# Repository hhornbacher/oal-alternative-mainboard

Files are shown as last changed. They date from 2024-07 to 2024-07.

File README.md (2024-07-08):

# Alternative mainboard for OpenAutoLab

The [OpenAutoLab](https://github.com/kauzerei/openautolab) is a automatic film processor developed by [@kauzerei](https://github.com/kauzerei).

I've designed an alternative mainboard based on an ESP32-S3 to also support transfer of development processes via BLE (and in future maybe WiFI with web interface).

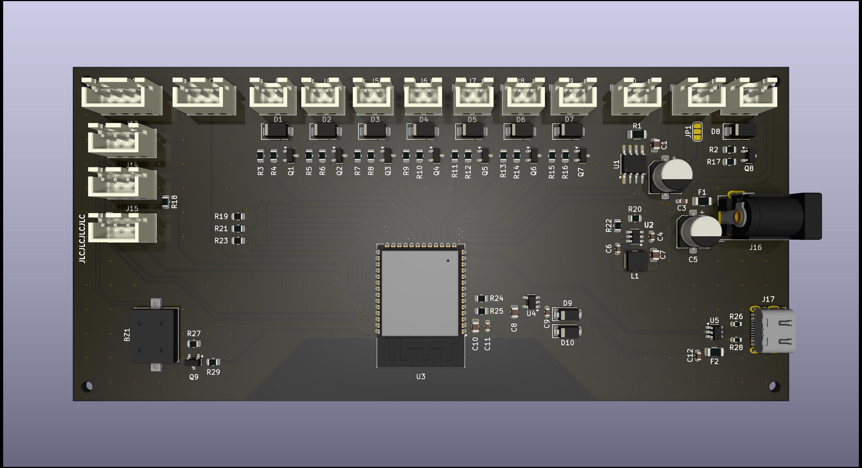
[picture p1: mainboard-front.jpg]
PCB rendering front


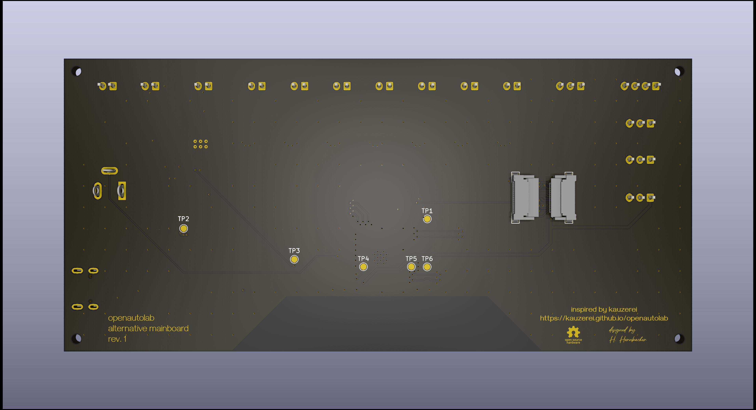
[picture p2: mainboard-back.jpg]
PCB rendering back


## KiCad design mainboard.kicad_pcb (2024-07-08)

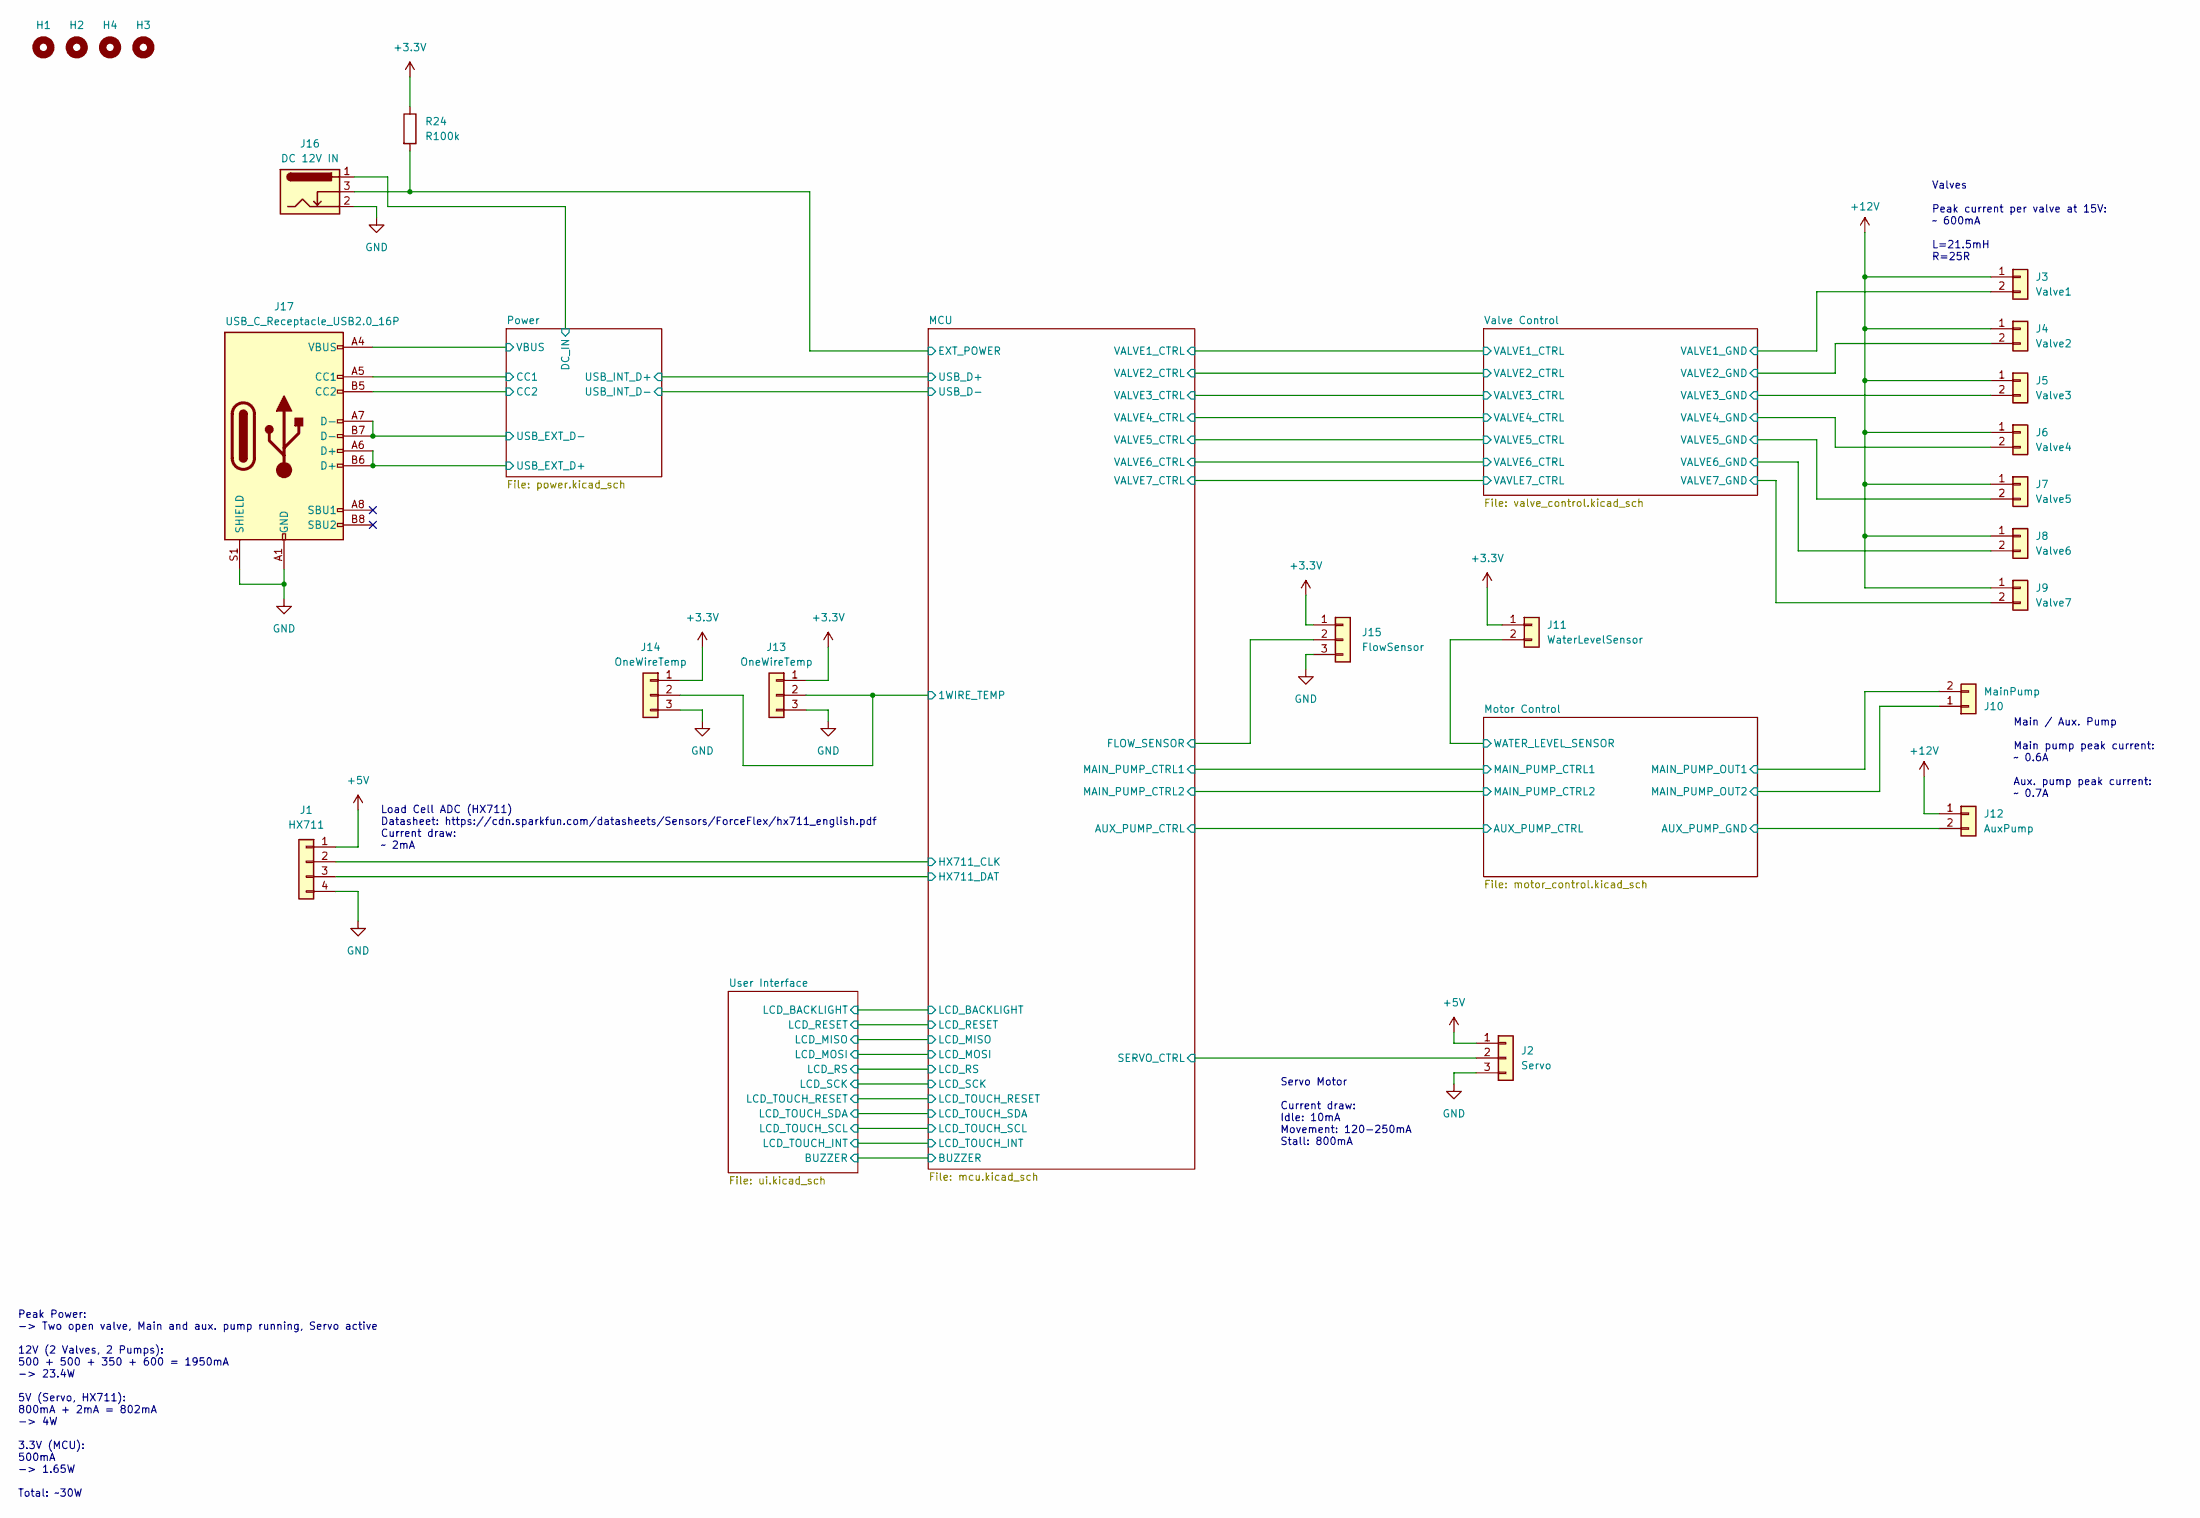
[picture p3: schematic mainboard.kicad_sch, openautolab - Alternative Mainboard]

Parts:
H1, H2, H3, H4: MountingHole; MountingHole_2.2mm_M2
J1: HX711; JST_XH_B4B-XH-A_1x04_P2.50mm_Vertical
J2: Servo; JST_XH_B3B-XH-A_1x03_P2.50mm_Vertical
J3: Valve1; JST_XH_B2B-XH-A_1x02_P2.50mm_Vertical
J4: Valve2; JST_XH_B2B-XH-A_1x02_P2.50mm_Vertical
J5: Valve3; JST_XH_B2B-XH-A_1x02_P2.50mm_Vertical
J6: Valve4; JST_XH_B2B-XH-A_1x02_P2.50mm_Vertical
J7: Valve5; JST_XH_B2B-XH-A_1x02_P2.50mm_Vertical
J8: Valve6; JST_XH_B2B-XH-A_1x02_P2.50mm_Vertical
J9: Valve7; JST_XH_B2B-XH-A_1x02_P2.50mm_Vertical
J10: MainPump; JST_XH_B2B-XH-A_1x02_P2.50mm_Vertical
J11: WaterLevelSensor; JST_XH_B2B-XH-A_1x02_P2.50mm_Vertical
J12: AuxPump; JST_XH_B2B-XH-A_1x02_P2.50mm_Vertical
J13, J14: OneWireTemp; JST_XH_B3B-XH-A_1x03_P2.50mm_Vertical
J15: FlowSensor; JST_XH_B3B-XH-A_1x03_P2.50mm_Vertical
J16: DC 12V IN; BarrelJack_Wuerth_6941xx301002; Mouser Part Number 710-694106301002
J17: USB_C_Receptacle_USB2.0_16P; USB_C_Receptacle_JAE_DX07S016JA1R1500; Mouser Part Number 656-DX07S016JA1R1500
R24: R100k; R_0805_2012Metric; Mouser Part Number 660-RK73B2ATTD104J

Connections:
+3.3V: J11.1, J13.1, J14.1, J15.1, R24.1; also elsewhere on the board
+5V: J1.1, J2.1; also elsewhere on the board
+12V: J3.1, J4.1, J5.1, J6.1, J7.1, J8.1, J9.1, J12.1; also elsewhere on the board
/MCU/1WIRE_TEMP: J13.2, J14.2; also elsewhere on the board
/MCU/EXT_POWER: J16.3, R24.2; also elsewhere on the board
/MCU/FLOW_SENSOR: J15.2; also elsewhere on the board
/MCU/HX711_CLK: J1.2; also elsewhere on the board
/MCU/HX711_DAT: J1.3; also elsewhere on the board
/MCU/SERVO_CTRL: J2.2; also elsewhere on the board
/Motor Control/AUX_PUMP_GND: J12.2; also elsewhere on the board
/Motor Control/MAIN_PUMP_OUT1: J10.2; also elsewhere on the board
/Motor Control/MAIN_PUMP_OUT2: J10.1; also elsewhere on the board
/Motor Control/WATER_LEVEL_SENSOR: J11.2; also elsewhere on the board
/Power/CC1: J17.A5 (CC1); also elsewhere on the board
/Power/CC2: J17.B5 (CC2); also elsewhere on the board
/Power/DC_IN: J16.1; also elsewhere on the board
/Power/USB_EXT_D+: J17.A6 (D+), J17.B6 (D+); also elsewhere on the board
/Power/USB_EXT_D-: J17.A7 (D-), J17.B7 (D-); also elsewhere on the board
/Power/VBUS: J17.A4 (VBUS), J17.A9 (VBUS), J17.B4 (VBUS), J17.B9 (VBUS); also elsewhere on the board
/Valve Control/VALVE1_GND: J3.2; also elsewhere on the board
/Valve Control/VALVE2_GND: J4.2; also elsewhere on the board
/Valve Control/VALVE3_GND: J5.2; also elsewhere on the board
/Valve Control/VALVE4_GND: J6.2; also elsewhere on the board
/Valve Control/VALVE5_GND: J7.2; also elsewhere on the board
/Valve Control/VALVE6_GND: J8.2; also elsewhere on the board
/Valve Control/VALVE7_GND: J9.2; also elsewhere on the board
GND: J1.4, J2.3, J13.3, J14.3, J15.3, J16.2, J17.A1 (GND), J17.A12 (GND), J17.B1 (GND), J17.B12 (GND), J17.S1 (SHIELD); also elsewhere on the board

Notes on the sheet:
Peak Power: -> Two open valve, Main and aux. pump running, Servo active 12V (2 Valves, 2 Pumps): 500 + 500 + 350 + 600 = 1950mA -> 23.4W 5V (Servo, HX711): 800mA + 2mA = 802mA -> 4W 3.3V (MCU): 500mA -> 1.65W Total: ~30W
Load Cell ADC (HX711) Datasheet: https://cdn.sparkfun.com/datasheets/Sensors/ForceFlex/hx711_english.pdf Current draw: ~ 2mA
Valves Peak current per valve at 15V: ~ 600mA L=21.5mH R=25R
Servo Motor Current draw: Idle: 10mA Movement: 120-250mA Stall: 800mA
Main / Aux. Pump Main pump peak current: ~ 0.6A Aux. pump peak current: ~ 0.7A

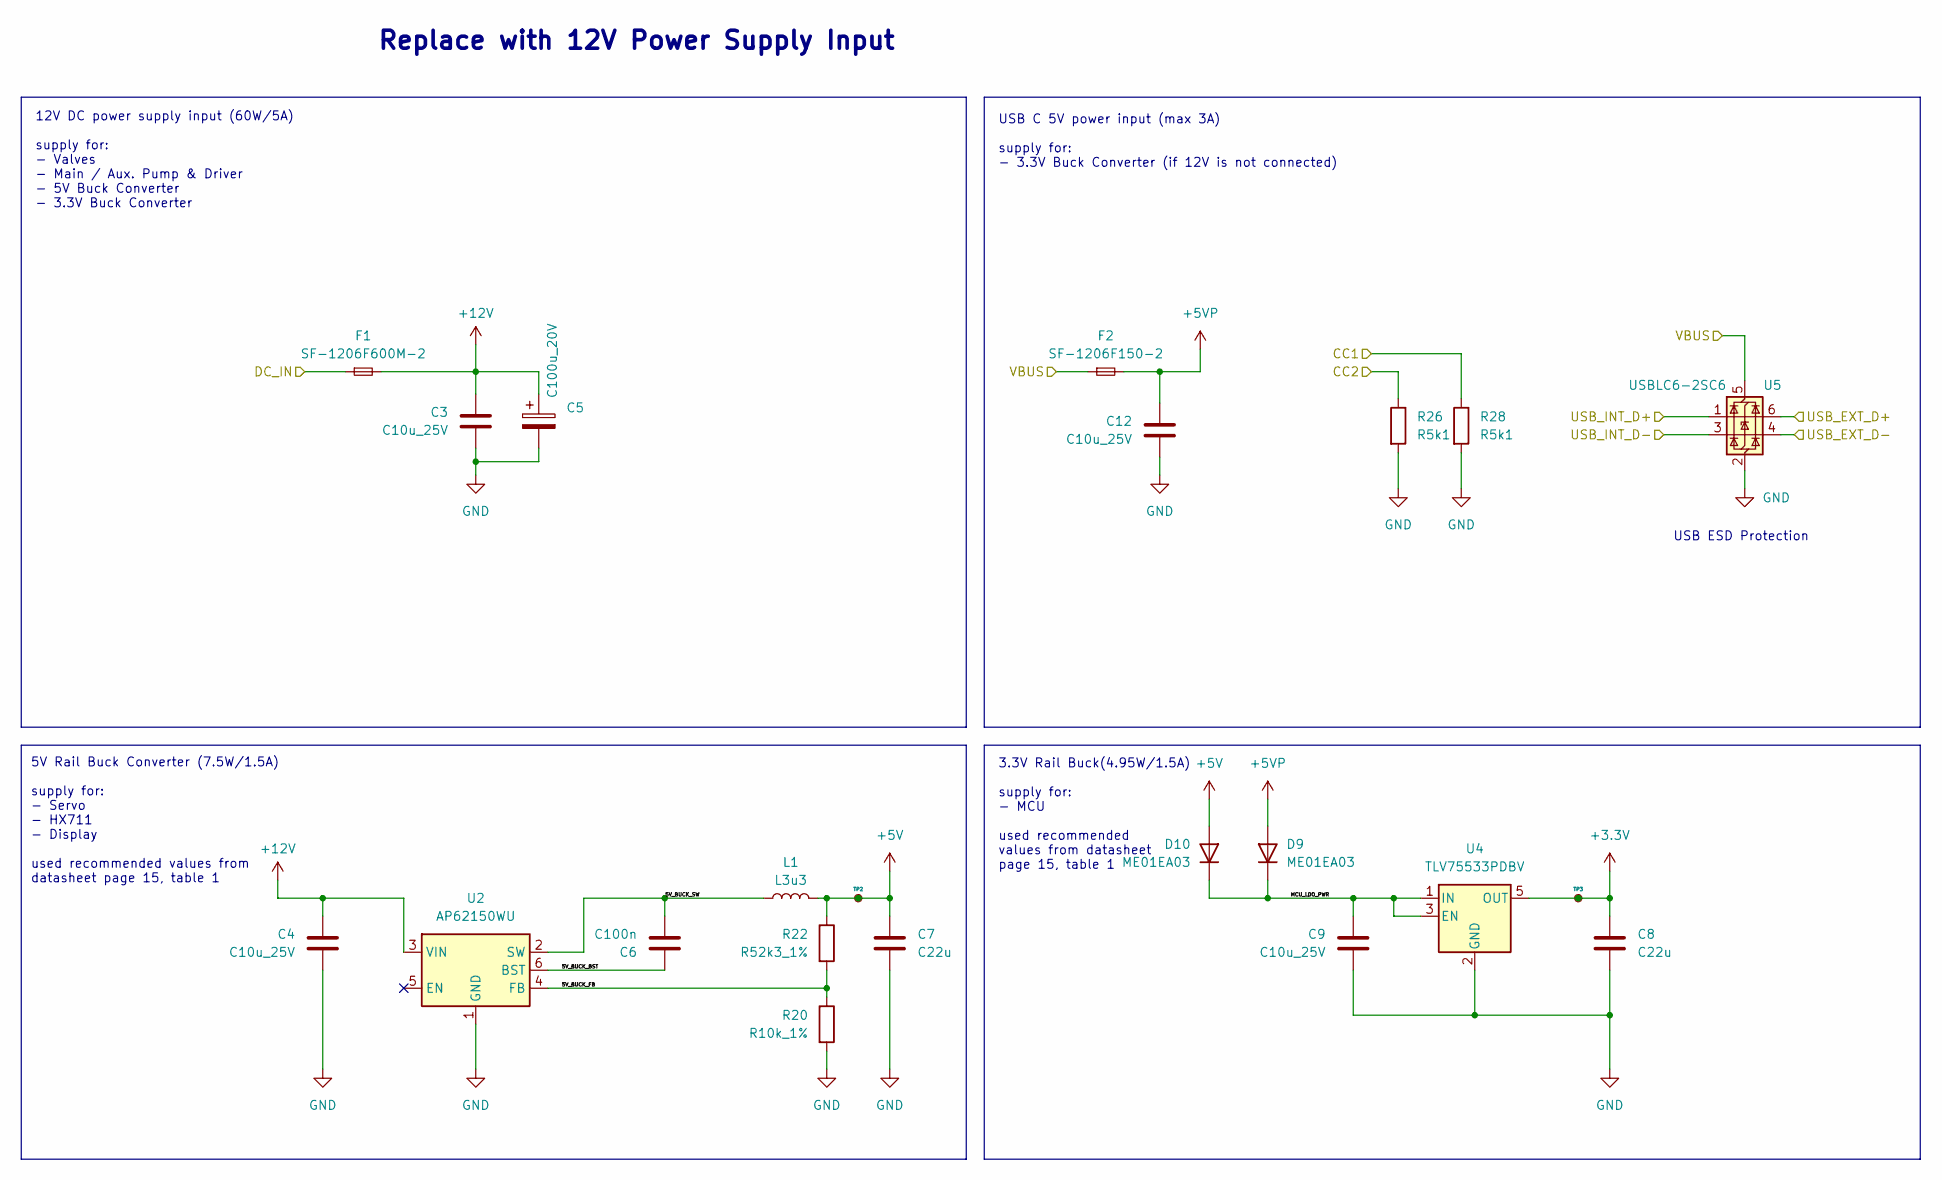
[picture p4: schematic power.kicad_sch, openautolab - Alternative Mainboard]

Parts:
C3, C4, C9, C12: C10u_25V; C_0603_1608Metric; Mouser Part Number 81-GRM188R61E106KA3J
C5: C100u_20V; CP_Elec_6.3x5.9; Mouser Part Number 647-PCM1D101MCL1GS
C6: C100n; C_0603_1608Metric; Mouser Part Number 80-C0603C104K3R7867
C7, C8: C22u; C_0805_2012Metric; Mouser Part Number 187-CL21A226MQQNNNF
D9, D10: ME01EA03; D_SOD-128; Mouser Part Number 581-ME01EA03
F1: SF-1206F600M-2; Fuse_1206_3216Metric; Mouser Part Number 652-SF-1206F600M-2
F2: SF-1206F150-2; Fuse_1206_3216Metric; Mouser Part Number 652-SF-1206F150-2
L1: L3u3; L_Coilcraft_LPS4018; Mouser Part Number 994-LPS4018-332MRC
R20: R10k_1%; R_0805_2012Metric; Mouser Part Number 71-CRCW0805-10K-E3
R22: R52k3_1%; R_0805_2012Metric; Mouser Part Number 652-CR0805FX-5232ELF
R26, R28: R5k1; R_0603_1608Metric; Mouser Part Number 667-ERJ-3EKF5101V
TP2, TP3: TestPoint_Small; TestPoint_Pad_D1.5mm
U2: AP62150WU; TSOT-23-6; Mouser Part Number 621-AP62150WU-7
U4: TLV75533PDBV; SOT-23-5; Mouser Part Number 595-TLV75533PDBVR
U5: USBLC6-2SC6; SOT-23-6; Mouser Part Number 511-USBLC6-2SC6

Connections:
+3.3V: C8.1, TP3.1, U4.5 (OUT); also elsewhere on the board
+5V: C7.1, D10.2 (A), L1.2, R22.1, TP2.1; also elsewhere on the board
+5VP: C12.1, D9.2 (A), F2.2
+12V: C3.1, C4.1, C5.1, F1.2, U2.3 (VIN); also elsewhere on the board
/MCU/USB_D+: U5.1 (I/O1); also elsewhere on the board
/MCU/USB_D-: U5.3 (I/O2); also elsewhere on the board
/Power/5V_BUCK_BST: C6.2, U2.6 (BST)
/Power/5V_BUCK_FB: R20.1, R22.2, U2.4 (FB)
/Power/5V_BUCK_SW: C6.1, L1.1, U2.2 (SW)
/Power/CC1: R28.1; also elsewhere on the board
/Power/CC2: R26.1; also elsewhere on the board
/Power/DC_IN: F1.1; also elsewhere on the board
/Power/MCU_LDO_PWR: C9.1, D9.1 (K), D10.1 (K), U4.1 (IN), U4.3 (EN)
/Power/USB_EXT_D+: U5.6 (I/O1); also elsewhere on the board
/Power/USB_EXT_D-: U5.4 (I/O2); also elsewhere on the board
/Power/VBUS: F2.1, U5.5 (VBUS); also elsewhere on the board
GND: C3.2, C4.2, C5.2, C7.2, C8.2, C9.2, C12.2, R20.2, R26.2, R28.2, U2.1 (GND), U4.2 (GND), U5.2 (GND); also elsewhere on the board

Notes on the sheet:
5V Rail Buck Converter (7.5W/1.5A) supply for: - Servo - HX711 - Display used recommended values from datasheet page 15, table 1
USB C 5V power input (max 3A) supply for: - 3.3V Buck Converter (if 12V is not connected)
3.3V Rail Buck(4.95W/1.5A) supply for: - MCU used recommended values from datasheet page 15, table 1
USB ESD Protection
12V DC power supply input (60W/5A) supply for: - Valves - Main / Aux. Pump & Driver - 5V Buck Converter - 3.3V Buck Converter
Replace with 12V Power Supply Input

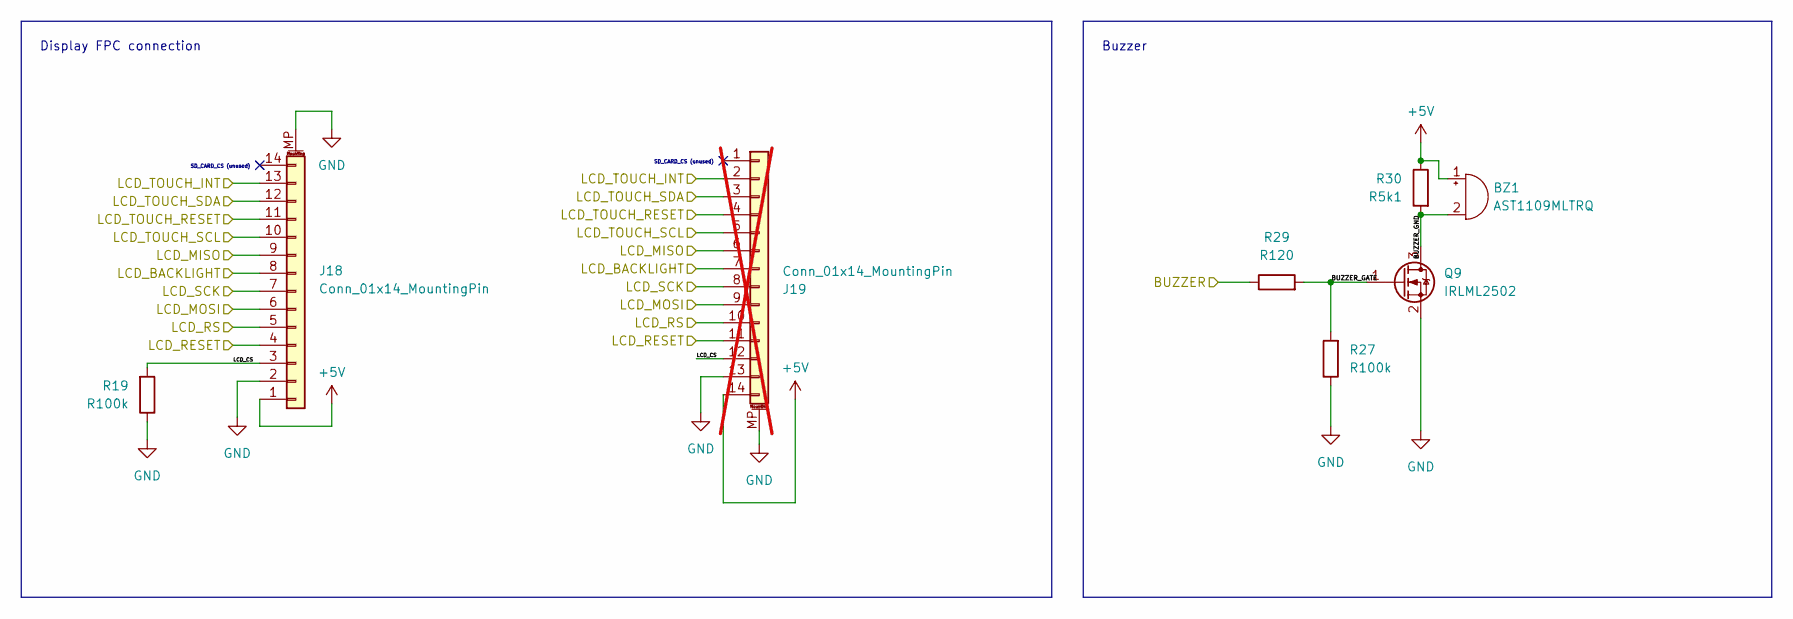
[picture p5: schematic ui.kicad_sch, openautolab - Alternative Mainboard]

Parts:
BZ1: AST1109MLTRQ; Buzzer_Mallory_AST1109MLTRQ; Mouser Part Number 539-AST1109MLTRQ
J18: Conn_01x14_MountingPin; XF2M-1415-1A; Mouser Part Number 653-XF2M-1415-1A
J19: Conn_01x14_MountingPin; XF2M-1415-1A; Mouser Part Number 653-XF2M-1415-1A; not fitted
Q9: IRLML2502; SOT-23; Mouser Part Number 942-IRLML2502TRPBF
R19, R27: R100k; R_0805_2012Metric; Mouser Part Number 660-RK73B2ATTD104J
R29: R120; R_0805_2012Metric; Mouser Part Number 603-AC0805FR-07120RL
R30: R5k1; R_0603_1608Metric; Mouser Part Number 667-ERJ-3EKF5101V

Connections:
+5V: BZ1.1 (+), J18.1, J19.14, R30.1; also elsewhere on the board
/MCU/BUZZER: R29.1; also elsewhere on the board
/MCU/LCD_BACKLIGHT: J18.8, J19.7; also elsewhere on the board
/MCU/LCD_MISO: J18.9, J19.6; also elsewhere on the board
/MCU/LCD_MOSI: J18.6, J19.9; also elsewhere on the board
/MCU/LCD_RESET: J18.4, J19.11; also elsewhere on the board
/MCU/LCD_RS: J18.5, J19.10; also elsewhere on the board
/MCU/LCD_SCK: J18.7, J19.8; also elsewhere on the board
/MCU/LCD_TOUCH_INT: J18.13, J19.2; also elsewhere on the board
/MCU/LCD_TOUCH_RESET: J18.11, J19.4; also elsewhere on the board
/MCU/LCD_TOUCH_SCL: J18.10, J19.5; also elsewhere on the board
/MCU/LCD_TOUCH_SDA: J18.12, J19.3; also elsewhere on the board
/User Interface/BUZZER_GATE: Q9.1 (G), R27.2, R29.2
/User Interface/BUZZER_GND: BZ1.2 (-), Q9.3 (D), R30.2
/User Interface/LCD_CS: J18.3, J19.12, R19.2
GND: J18.2, J18.MP (MountPin), J19.13, J19.MP (MountPin), Q9.2 (S), R19.1, R27.1; also elsewhere on the board

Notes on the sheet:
SD_CARD_CS (unused)
Display FPC connection
Buzzer

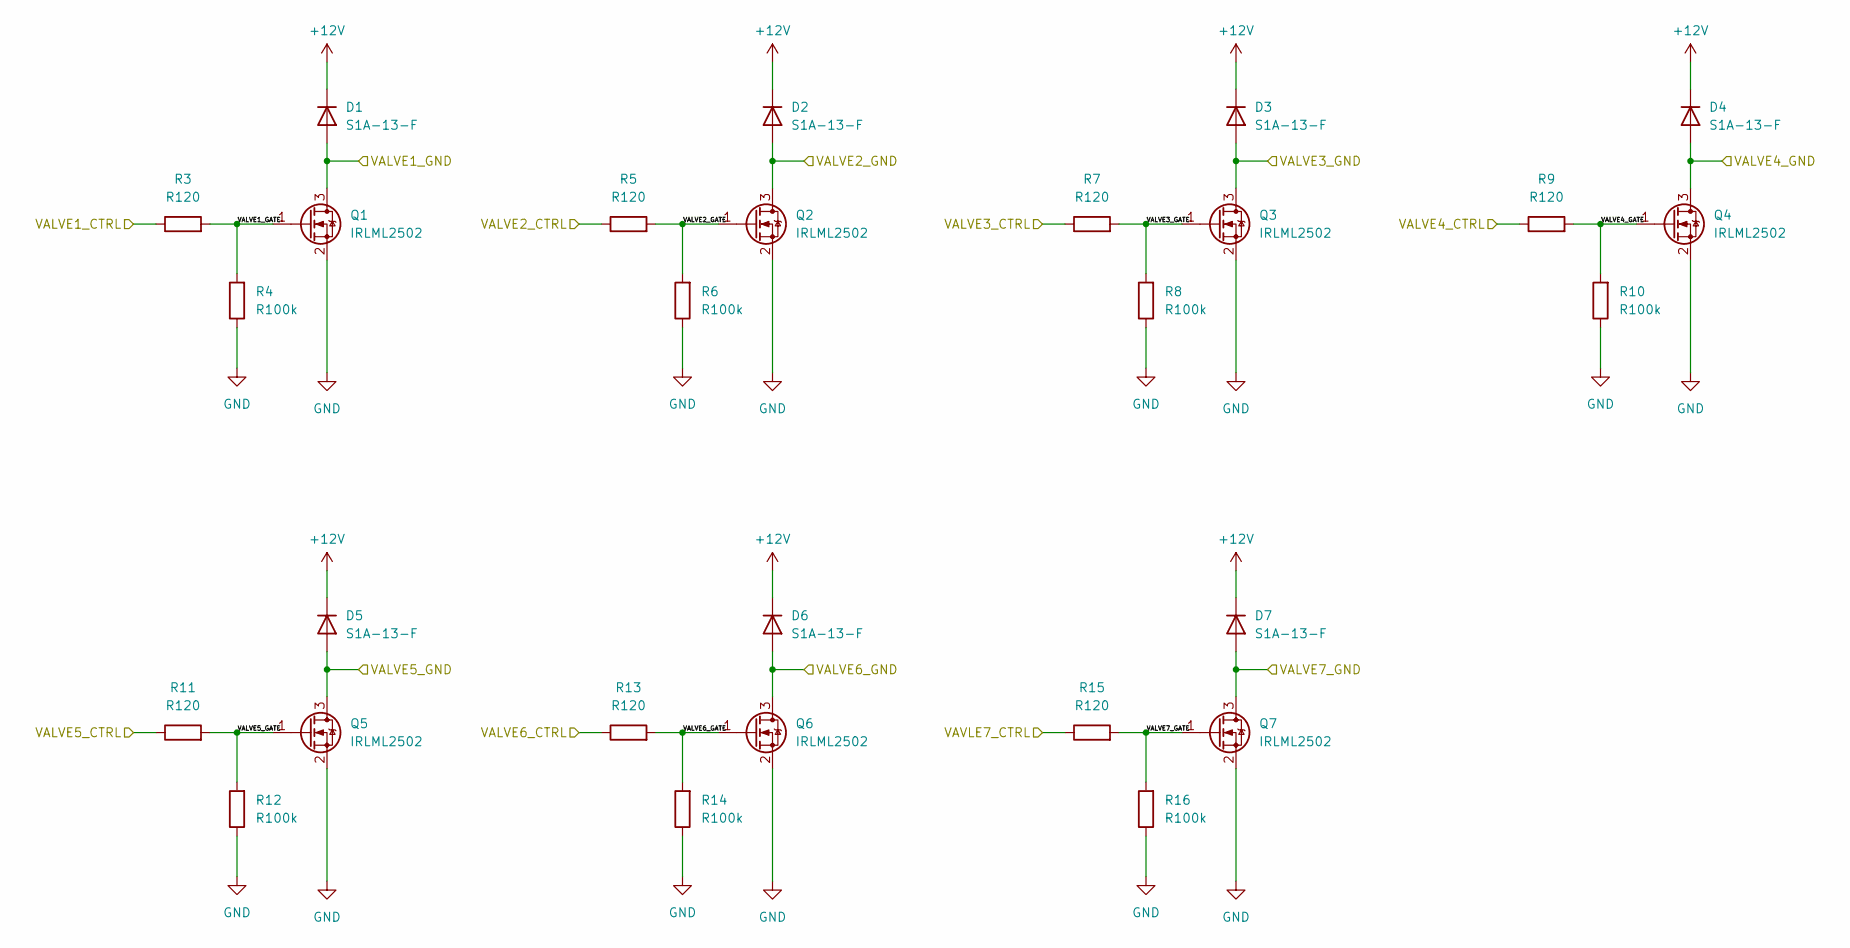
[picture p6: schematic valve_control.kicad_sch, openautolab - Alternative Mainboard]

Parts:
D1, D2, D3, D4, D5, D6, D7: S1A-13-F; D_SMA; Mouser Part Number 621-ES1A-F
Q1, Q2, Q3, Q4, Q5, Q6, Q7: IRLML2502; SOT-23; Mouser Part Number 942-IRLML2502TRPBF
R3, R5, R7, R9, R11, R13, R15: R120; R_0805_2012Metric; Mouser Part Number 603-AC0805FR-07120RL
R4, R6, R8, R10, R12, R14, R16: R100k; R_0805_2012Metric; Mouser Part Number 660-RK73B2ATTD104J

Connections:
+12V: D1.1 (K), D2.1 (K), D3.1 (K), D4.1 (K), D5.1 (K), D6.1 (K), D7.1 (K); also elsewhere on the board
/MCU/VALVE1_CTRL: R3.1; also elsewhere on the board
/MCU/VALVE2_CTRL: R5.1; also elsewhere on the board
/MCU/VALVE3_CTRL: R7.1; also elsewhere on the board
/MCU/VALVE4_CTRL: R9.1; also elsewhere on the board
/MCU/VALVE5_CTRL: R11.1; also elsewhere on the board
/MCU/VALVE6_CTRL: R13.1; also elsewhere on the board
/MCU/VALVE7_CTRL: R15.1; also elsewhere on the board
/Valve Control/VALVE1_GATE: Q1.1 (G), R3.2, R4.2
/Valve Control/VALVE1_GND: D1.2 (A), Q1.3 (D); also elsewhere on the board
/Valve Control/VALVE2_GATE: Q2.1 (G), R5.2, R6.2
/Valve Control/VALVE2_GND: D2.2 (A), Q2.3 (D); also elsewhere on the board
/Valve Control/VALVE3_GATE: Q3.1 (G), R7.2, R8.2
/Valve Control/VALVE3_GND: D3.2 (A), Q3.3 (D); also elsewhere on the board
/Valve Control/VALVE4_GATE: Q4.1 (G), R9.2, R10.2
/Valve Control/VALVE4_GND: D4.2 (A), Q4.3 (D); also elsewhere on the board
/Valve Control/VALVE5_GATE: Q5.1 (G), R11.2, R12.2
/Valve Control/VALVE5_GND: D5.2 (A), Q5.3 (D); also elsewhere on the board
/Valve Control/VALVE6_GATE: Q6.1 (G), R13.2, R14.2
/Valve Control/VALVE6_GND: D6.2 (A), Q6.3 (D); also elsewhere on the board
/Valve Control/VALVE7_GATE: Q7.1 (G), R15.2, R16.2
/Valve Control/VALVE7_GND: D7.2 (A), Q7.3 (D); also elsewhere on the board
GND: Q1.2 (S), Q2.2 (S), Q3.2 (S), Q4.2 (S), Q5.2 (S), Q6.2 (S), Q7.2 (S), R4.1, R6.1, R8.1, R10.1, R12.1, R14.1, R16.1; also elsewhere on the board

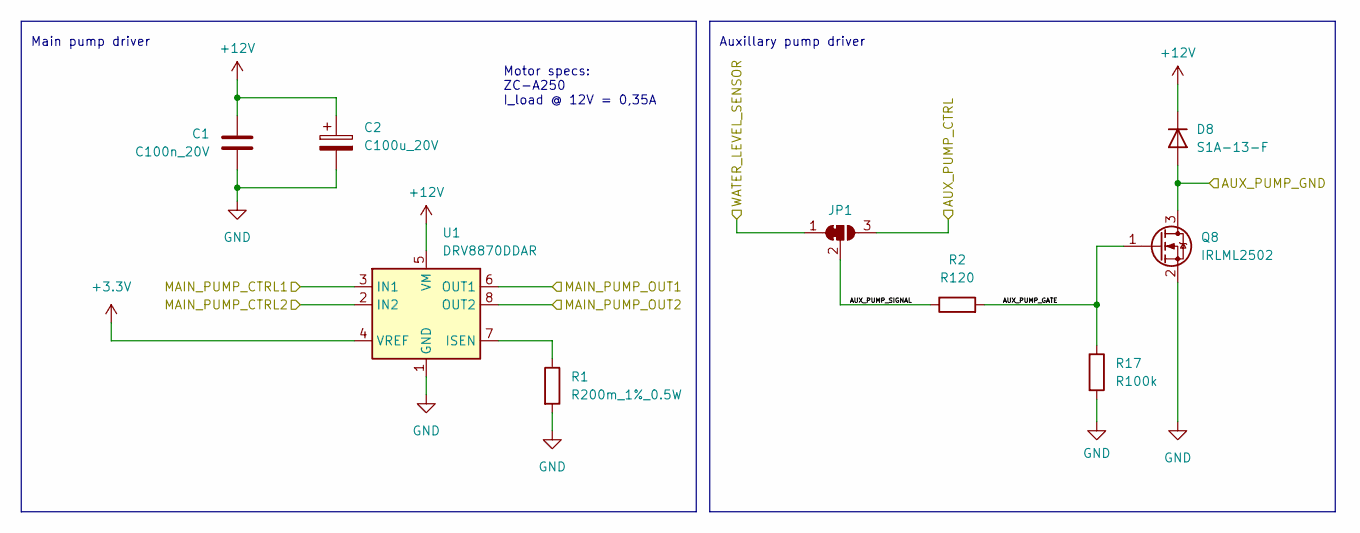
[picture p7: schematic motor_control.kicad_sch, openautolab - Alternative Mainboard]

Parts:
C1: C100n_20V; C_0805_2012Metric; Mouser Part Number 187-CL21B104KACNNNC
C2: C100u_20V; CP_Elec_6.3x5.9; Mouser Part Number 647-PCM1D101MCL1GS
D8: S1A-13-F; D_SMA; Mouser Part Number 621-ES1A-F
JP1: SolderJumper_3_Bridged12; SolderJumper-3_P1.3mm_Bridged12_RoundedPad1.0x1.5mm_NumberL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
Q8: IRLML2502; SOT-23; Mouser Part Number 942-IRLML2502TRPBF
R1: R200m_1%_0.5W; R_1206_3216Metric; Mouser Part Number 504-MFLA1206R2000FS
R2: R120; R_0805_2012Metric; Mouser Part Number 603-AC0805FR-07120RL
R17: R100k; R_0805_2012Metric; Mouser Part Number 660-RK73B2ATTD104J
U1: DRV8870DDAR; Texas_HTSOP-8-1EP_3.9x4.9mm_P1.27mm_EP2.95x4.9mm_Mask2.4x3.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; Mouser Part Number 595-DRV8870DDAR

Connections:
+3.3V: U1.4 (VREF); also elsewhere on the board
+12V: C1.1, C2.1, D8.1 (K), U1.5 (VM); also elsewhere on the board
/MCU/AUX_PUMP_CTRL: JP1.3 (B); also elsewhere on the board
/MCU/MAIN_PUMP_CTRL1: U1.3 (IN1); also elsewhere on the board
/MCU/MAIN_PUMP_CTRL2: U1.2 (IN2); also elsewhere on the board
/Motor Control/AUX_PUMP_GATE: Q8.1 (G), R2.2, R17.1
/Motor Control/AUX_PUMP_GND: D8.2 (A), Q8.3 (D); also elsewhere on the board
/Motor Control/AUX_PUMP_SIGNAL: JP1.2 (C), R2.1
/Motor Control/MAIN_PUMP_OUT1: U1.6 (OUT1); also elsewhere on the board
/Motor Control/MAIN_PUMP_OUT2: U1.8 (OUT2); also elsewhere on the board
/Motor Control/WATER_LEVEL_SENSOR: JP1.1 (A); also elsewhere on the board
GND: C1.2, C2.2, Q8.2 (S), R1.2, R17.2, U1.1 (GND), U1.9 (GND); also elsewhere on the board
unnamed: R1.1, U1.7 (ISEN)

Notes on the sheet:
Main pump driver
Motor specs: ZC-A250 I_load @ 12V = 0,35A
Auxillary pump driver

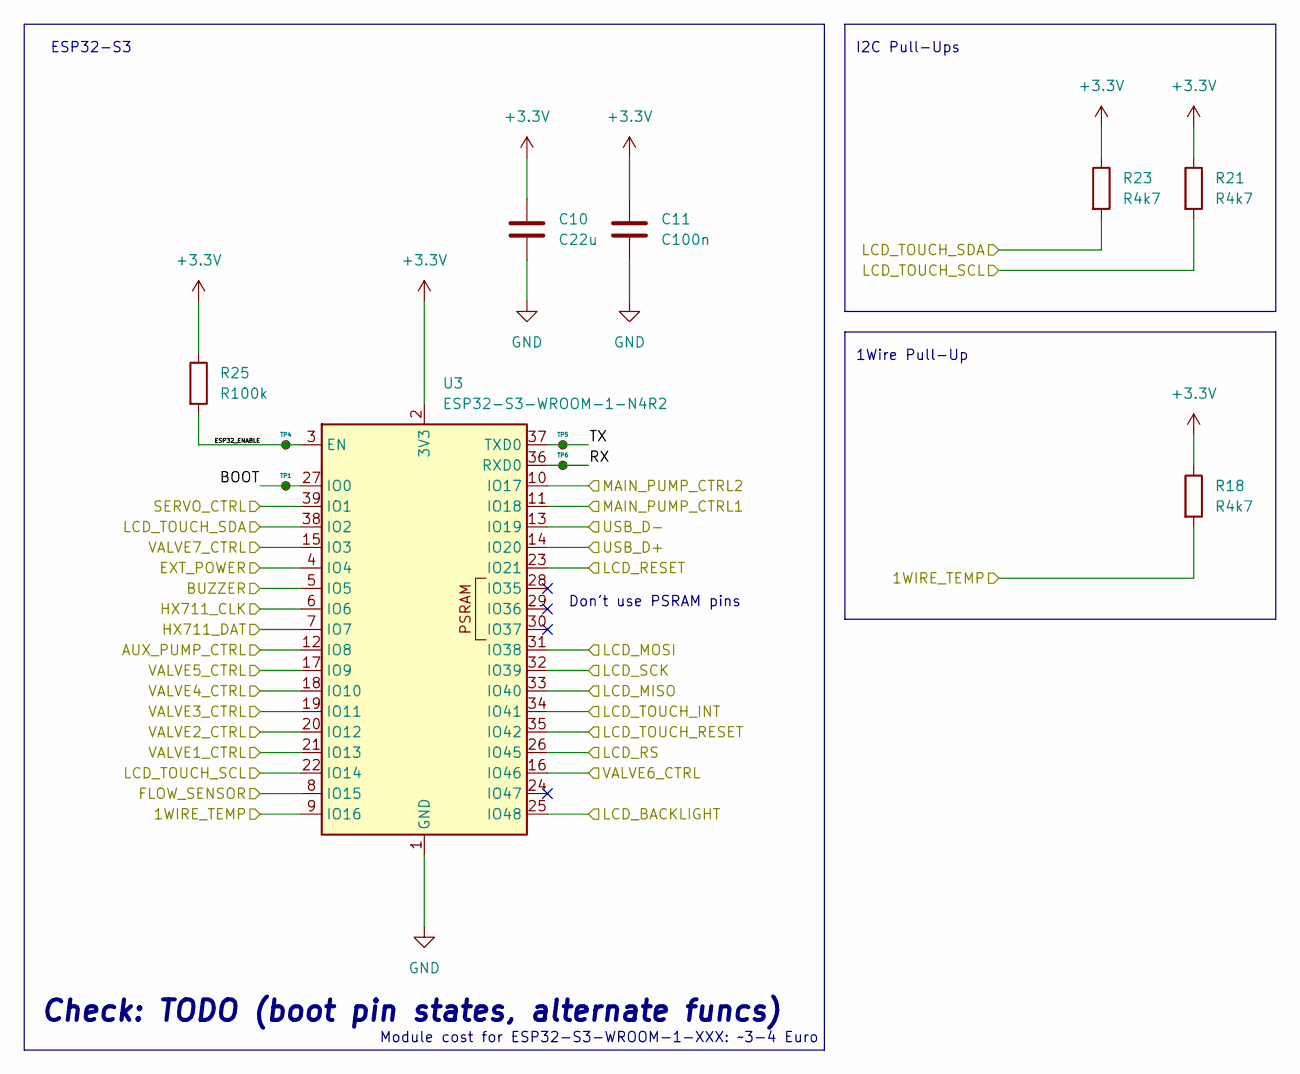
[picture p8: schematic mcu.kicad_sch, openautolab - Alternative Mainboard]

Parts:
C10: C22u; C_0805_2012Metric; Mouser Part Number 187-CL21A226MQQNNNF
C11: C100n; C_0603_1608Metric; Mouser Part Number 80-C0603C104K3R7867
R18, R21, R23: R4k7; R_0805_2012Metric; Mouser Part Number 279-CRGH0805F4K7
R25: R100k; R_0805_2012Metric; Mouser Part Number 660-RK73B2ATTD104J
TP1, TP4, TP5, TP6: TestPoint_Small; TestPoint_Pad_D1.5mm
U3: ESP32-S3-WROOM-1-N4R2; ESP32-S3-WROOM-1; Mouser Part Number 356-ESP32S3WROM1N4R2

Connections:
+3.3V: C10.1, C11.1, R18.1, R21.1, R23.1, R25.1, U3.2 (3V3); also elsewhere on the board
/MCU/1WIRE_TEMP: R18.2, U3.9 (IO16); also elsewhere on the board
/MCU/AUX_PUMP_CTRL: U3.12 (IO8); also elsewhere on the board
/MCU/BOOT: TP1.1, U3.27 (IO0)
/MCU/BUZZER: U3.5 (IO5); also elsewhere on the board
/MCU/ESP32_ENABLE: R25.2, TP4.1, U3.3 (EN)
/MCU/EXT_POWER: U3.4 (IO4); also elsewhere on the board
/MCU/FLOW_SENSOR: U3.8 (IO15); also elsewhere on the board
/MCU/HX711_CLK: U3.6 (IO6); also elsewhere on the board
/MCU/HX711_DAT: U3.7 (IO7); also elsewhere on the board
/MCU/LCD_BACKLIGHT: U3.25 (IO48); also elsewhere on the board
/MCU/LCD_MISO: U3.33 (IO40); also elsewhere on the board
/MCU/LCD_MOSI: U3.31 (IO38); also elsewhere on the board
/MCU/LCD_RESET: U3.23 (IO21); also elsewhere on the board
/MCU/LCD_RS: U3.26 (IO45); also elsewhere on the board
/MCU/LCD_SCK: U3.32 (IO39); also elsewhere on the board
/MCU/LCD_TOUCH_INT: U3.34 (IO41); also elsewhere on the board
/MCU/LCD_TOUCH_RESET: U3.35 (IO42); also elsewhere on the board
/MCU/LCD_TOUCH_SCL: R21.2, U3.22 (IO14); also elsewhere on the board
/MCU/LCD_TOUCH_SDA: R23.2, U3.38 (IO2); also elsewhere on the board
/MCU/MAIN_PUMP_CTRL1: U3.11 (IO18); also elsewhere on the board
/MCU/MAIN_PUMP_CTRL2: U3.10 (IO17); also elsewhere on the board
/MCU/RX: TP6.1, U3.36 (RXD0)
/MCU/SERVO_CTRL: U3.39 (IO1); also elsewhere on the board
/MCU/TX: TP5.1, U3.37 (TXD0)
/MCU/USB_D+: U3.14 (IO20); also elsewhere on the board
/MCU/USB_D-: U3.13 (IO19); also elsewhere on the board
/MCU/VALVE1_CTRL: U3.21 (IO13); also elsewhere on the board
/MCU/VALVE2_CTRL: U3.20 (IO12); also elsewhere on the board
/MCU/VALVE3_CTRL: U3.19 (IO11); also elsewhere on the board
/MCU/VALVE4_CTRL: U3.18 (IO10); also elsewhere on the board
/MCU/VALVE5_CTRL: U3.17 (IO9); also elsewhere on the board
/MCU/VALVE6_CTRL: U3.16 (IO46); also elsewhere on the board
/MCU/VALVE7_CTRL: U3.15 (IO3); also elsewhere on the board
GND: C10.2, C11.2, U3.1 (GND), U3.40 (GND), U3.41 (GND); also elsewhere on the board

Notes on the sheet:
Module cost for ESP32-S3-WROOM-1-XXX: ~3-4 Euro
ESP32-S3
Don't use PSRAM pins
Check: TODO (boot pin states, alternate funcs)
1Wire Pull-Up
I2C Pull-Ups

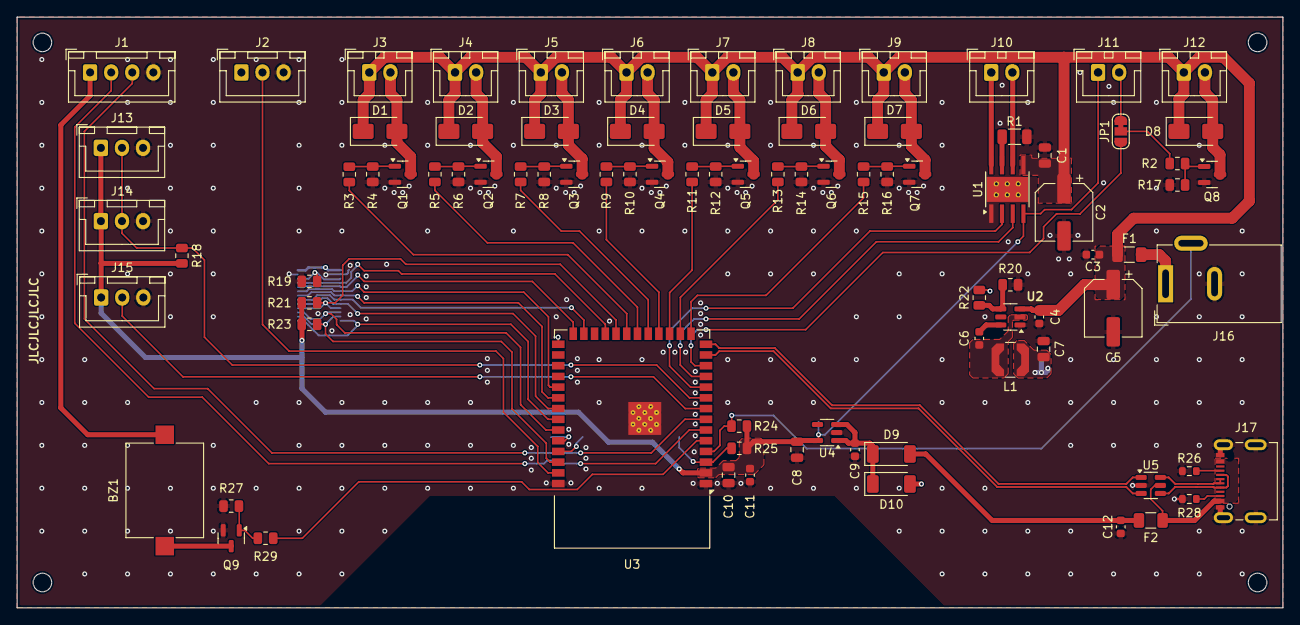
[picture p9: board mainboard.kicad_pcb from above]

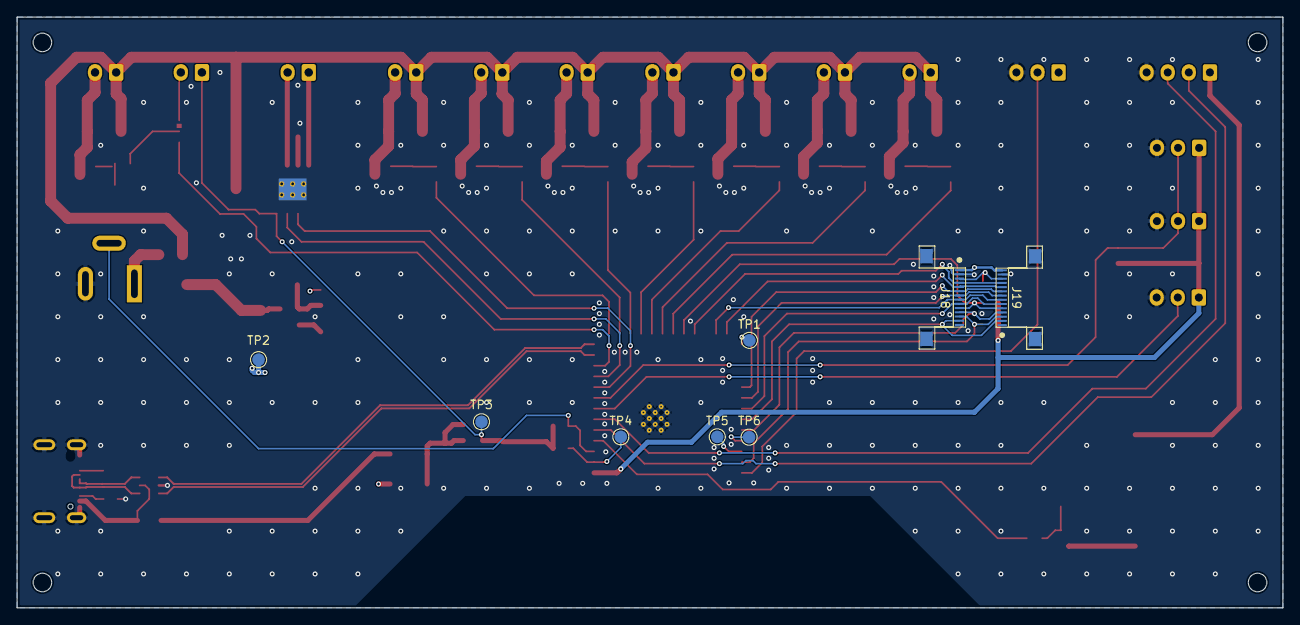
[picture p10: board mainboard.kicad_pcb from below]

Board: 4 copper layers, 150.0 x 70.0 mm, 99 parts (8 on the bottom side), 72 nets.

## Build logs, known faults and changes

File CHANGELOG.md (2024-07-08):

# Changelog

## Rev 2
- Add 5k1 resistor (R30) parallel to piezo (BZ1)
- Remove redundant 5V wire from bottom at buck converter (U2) 

## Rev 1
- Initial design

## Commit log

2024-04-03 Remove 12V buck converter and power rail
    [connectors.kicad_sch, motor_control.kicad_sch, power.kicad_sch]
2024-04-03 Remove redundant hierarchical labels
    [connectors.kicad_sch, mcu.kicad_sch, motor_control.kicad_sch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]
2024-04-03 Add ESP32-S3-WROOM-1, 5V rail and UI sheet
    [connectors.kicad_sch, mainboard.kicad_sch, mcu.kicad_sch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]
2024-04-30 Finish first design
    [connectors.kicad_sch, mainboard.kicad_pcb, mainboard.kicad_sch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]
2024-05-02 Add reminder to replace fuse
    [mainboard.kicad_sch]
2024-05-02 Add screen FPC to schematic and remove old OLED stuff
    [mainboard.kicad_sch, mcu.kicad_sch, ui.kicad_sch]
2024-05-02 Cleanup OLED stuff
    [mainboard.kicad_pcb]
2024-05-04 Fix LCD connector pin mapping and map them to MCU pins
    [mcu.kicad_sch, ui.kicad_sch]
2024-05-05 Improve USB ESD connection
    [mainboard.kicad_sch, power.kicad_sch]
2024-05-05 Remove bottom pads from USB footprint
2024-05-05 Work on improving USB & power layout
    [mainboard.kicad_pcb]
2024-05-06 Finalize pin mapping, cleanup and layout
    [mainboard.kicad_pcb, mcu.kicad_sch, power.kicad_sch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]
2024-05-06 Re-annotate parts by board
    [mainboard.kicad_pcb, mainboard.kicad_sch, mcu.kicad_sch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]
2024-05-12 Finish integration of TFT interface
    [mainboard.kicad_pcb, ui.kicad_sch]
2024-05-21 Redesign power rails to use barrel jack 12V input
    [mainboard.kicad_pcb, mainboard.kicad_sch, mcu.kicad_sch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]
2024-05-21 Cleanup layout and schematic
    [mainboard.kicad_pcb, mainboard.kicad_sch, mcu.kicad_sch]
2024-05-21 Reannotate geographically by layout
    [mainboard.kicad_pcb, mainboard.kicad_sch, mcu.kicad_sch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]
2024-05-22 Final checks and cleanup
    [mainboard.kicad_pcb, mainboard.kicad_sch, mcu.kicad_sch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]
2024-05-23 Fix revision
    [mainboard.kicad_pcb, mainboard.kicad_sch, mcu.kicad_sch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]
2024-06-07 Add GND via stitching
    [mainboard.kicad_pcb]
2024-06-07 - Start Rev 2 - Add 5k1 resistor (R30) parallel to piezo (BZ1) - Remove redundant 5V wire from bottom at buck converter (U2)
    [mainboard.kicad_pcb, mainboard.kicad_sch, mcu.kicad_sch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]
2024-07-08 Fix revision on board
    [mainboard.kicad_pcb]
